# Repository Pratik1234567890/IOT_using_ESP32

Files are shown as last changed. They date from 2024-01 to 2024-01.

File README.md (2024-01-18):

# IOT_using_ESP32

This is four layer circuit board

# Schmematic


# 3D viewer


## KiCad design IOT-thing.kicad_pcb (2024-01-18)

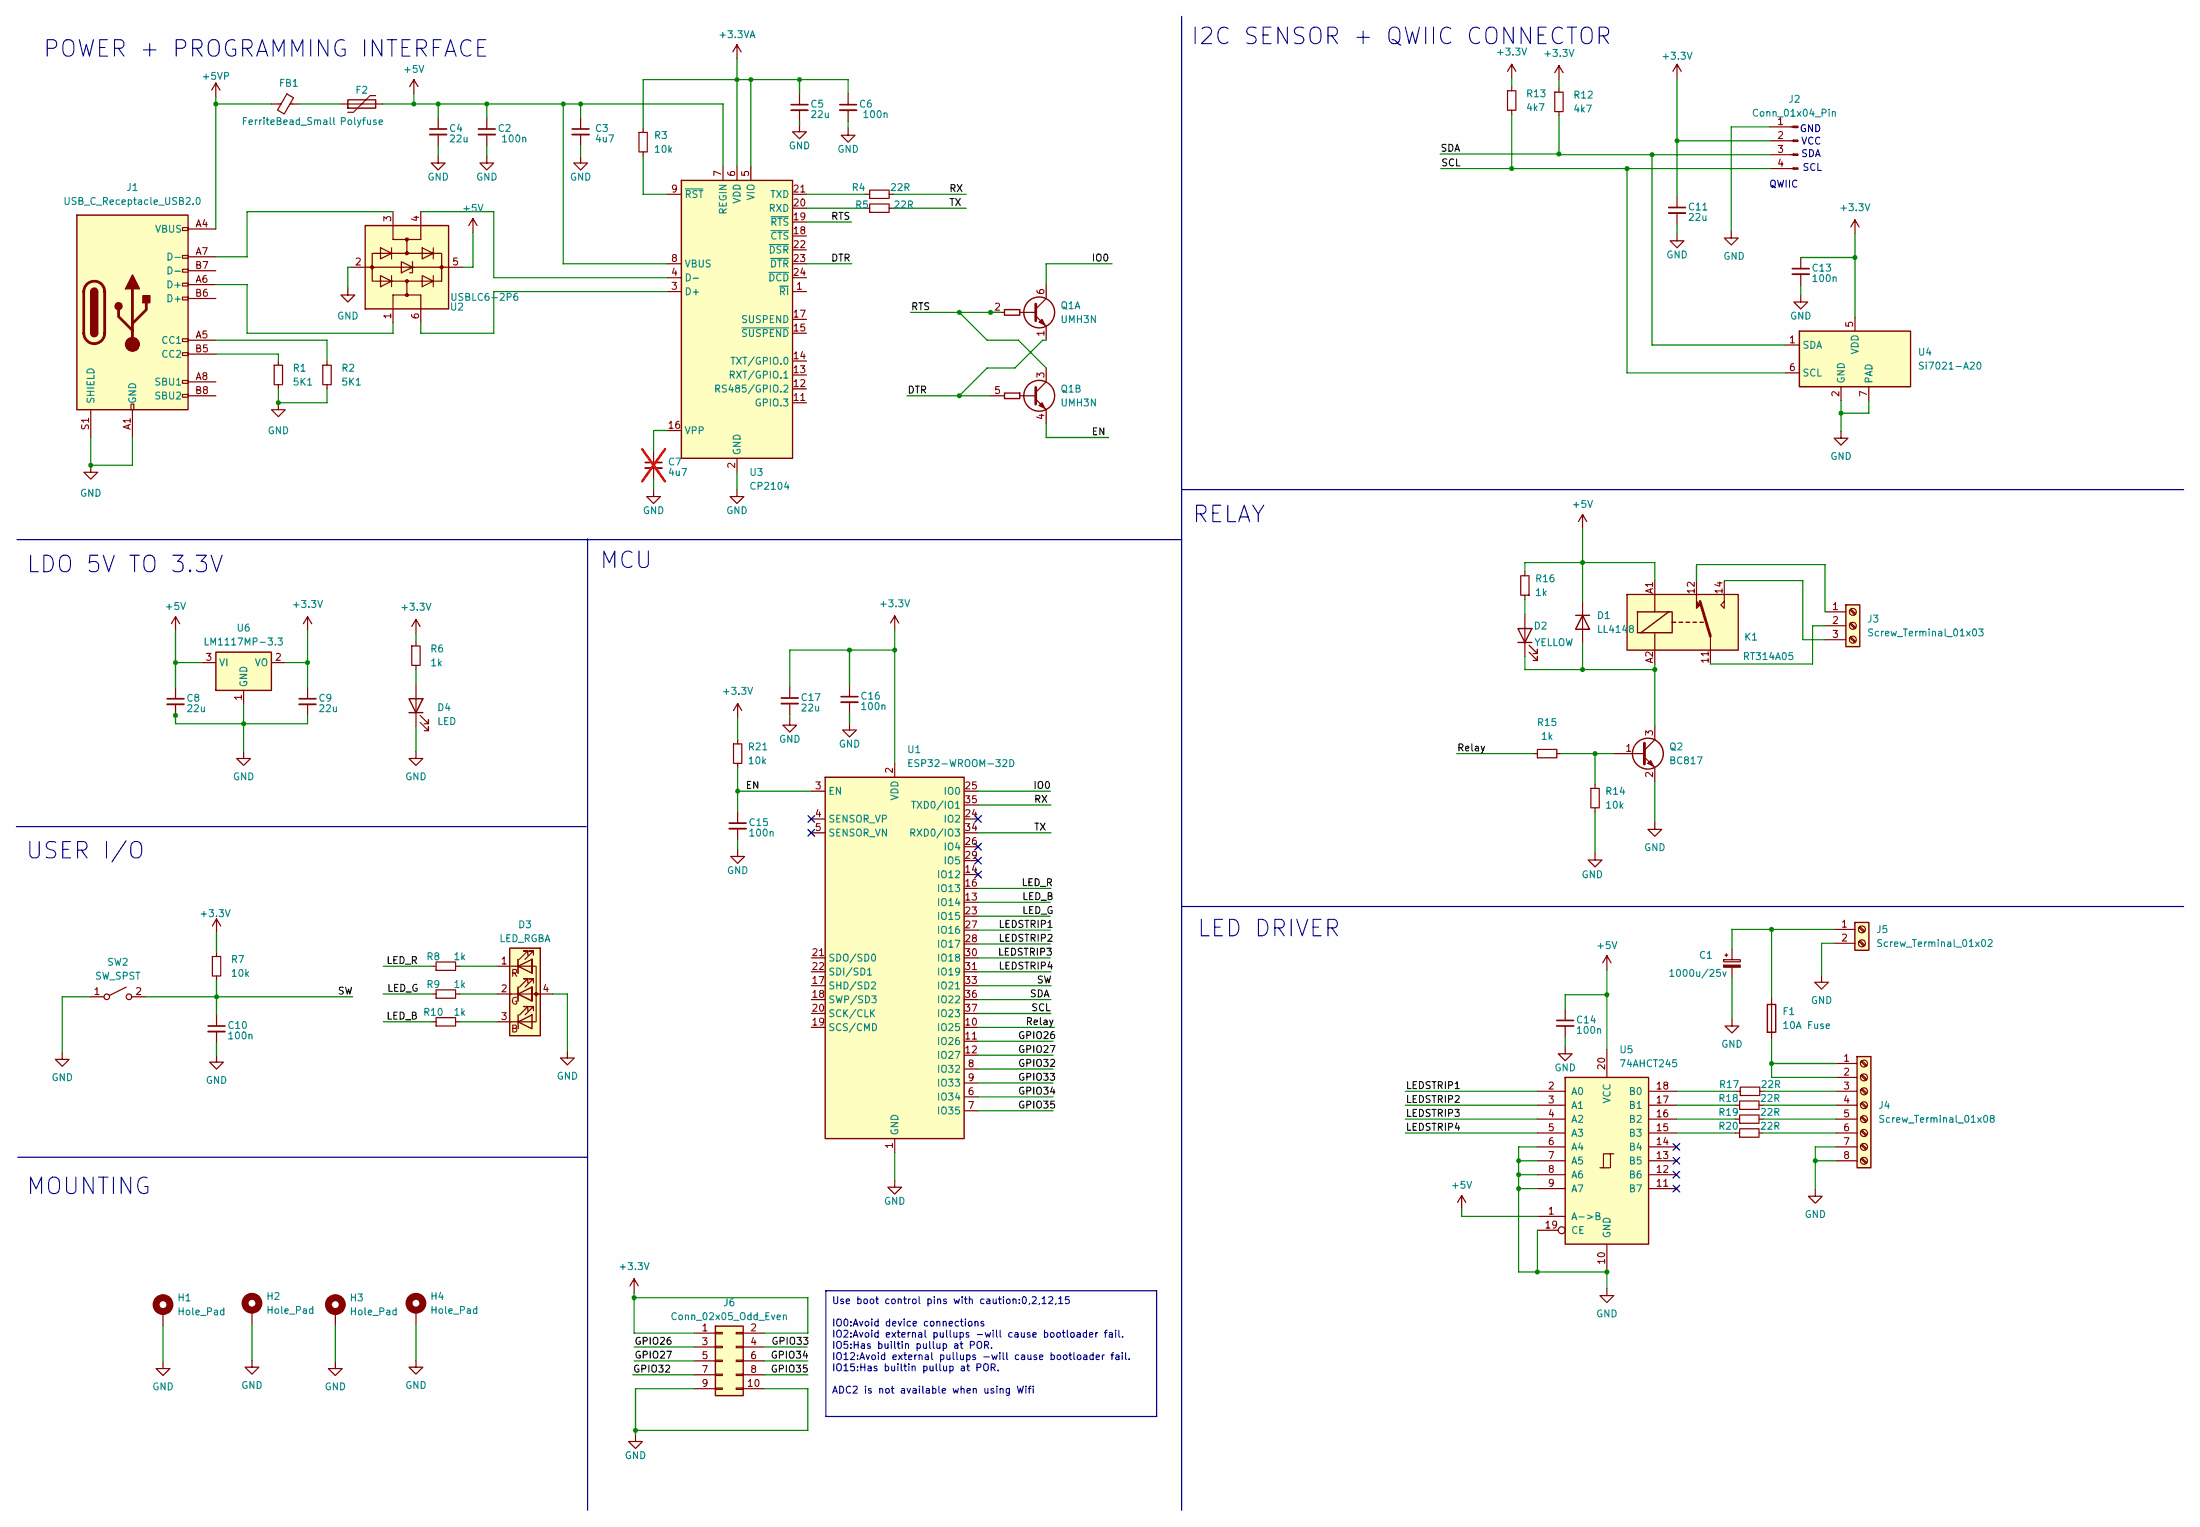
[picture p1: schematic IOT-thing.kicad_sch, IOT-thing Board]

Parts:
C1: 1000u/25v; CP_Radial_D10.0mm_P5.00mm
C2, C6, C10, C13, C14, C15, C16: 100n; C_0402_1005Metric_Pad0.74x0.62mm_HandSolder
C3: 4u7; C_0805_2012Metric_Pad1.18x1.45mm_HandSolder
C4, C5, C8, C9, C11, C17: 22u; C_0805_2012Metric_Pad1.18x1.45mm_HandSolder
C7: 4u7; C_0805_2012Metric_Pad1.18x1.45mm_HandSolder; not fitted
D1: LL4148; D_MiniMELF
D2: YELLOW; LED_0603_1608Metric_Pad1.05x0.95mm_HandSolder
D3: LED_RGBA; LED_RGB_Wuerth-PLCC4_3.2x2.8mm_150141M173100
D4: LED; LED_0603_1608Metric_Pad1.05x0.95mm_HandSolder
F1: 10A Fuse; Fuseholder_Clip-5x20mm_Bel_FC-203-22_Lateral_P17.80x5.00mm_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
F2: Polyfuse; Fuse_1206_3216Metric_Pad1.42x1.75mm_HandSolder
FB1: FerriteBead_Small; L_0603_1608Metric_Pad1.05x0.95mm_HandSolder
H1, H2, H3, H4: Hole_Pad; MountingHole_3.2mm_M3_Pad_Via
J1: USB_C_Receptacle_USB2.0; USB_C_Receptacle_HRO_TYPE-C-31-M-12
J2: Conn_01x04_Pin; JST_SH_SM04B-SRSS-TB_1x04-1MP_P1.00mm_Horizontal
J3: Screw_Terminal_01x03; TerminalBlock_Phoenix_MKDS-3-3-5.08_1x03_P5.08mm_Horizontal
J4: Screw_Terminal_01x08; TerminalBlock_Phoenix_MKDS-1,5-8_1x08_P5.00mm_Horizontal
J5: Screw_Terminal_01x02; TerminalBlock_Phoenix_MKDS-1,5-2-5.08_1x02_P5.08mm_Horizont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
J6: Conn_02x05_Odd_Even; PinHeader_2x05_P2.54mm_Vertical
K1: RT314A05; Relay_SPDT_Schrack-RT1-16A-FormC_RM5mm
Q1: UMH3N; SOT-363_SC-70-6
Q2: BC817; SOT-23
R1, R2: 5K1; R_0402_1005Metric_Pad0.72x0.64mm_HandSolder
R3, R7, R14, R21: 10k; R_0402_1005Metric_Pad0.72x0.64mm_HandSolder
R4, R5, R17, R18, R19, R20: 22R; R_0402_1005Metric_Pad0.72x0.64mm_HandSolder
R6, R8, R9, R10, R15, R16: 1k; R_0402_1005Metric_Pad0.72x0.64mm_HandSolder
R12, R13: 4k7; R_0402_1005Metric_Pad0.72x0.64mm_HandSolder
SW2: SW_SPST; SW_Push_1P1T_NO_6x6mm_H9.5mm
U1: ESP32-WROOM-32D
U2: USBLC6-2P6; SOT-666
U3: CP2104; QFN-24-1EP_4x4mm_P0.5mm_EP2.6x2.6mm
U4: Si7021-A20; DFN-6-1EP_3x3mm_P1mm_EP1.5x2.4mm
U5: 74AHCT245; DIP-20_W7.62mm
U6: LM1117MP-3.3; SOT-223-3_TabPin2

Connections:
+3.3V: C9.1, C11.1, C13.1, C16.1, C17.1, J2.2, J6.1, J6.2, R6.1, R7.1, R12.1, R13.1, R21.1, U1.2 (VDD), U4.5 (VDD), U6.2 (VO)
+3.3VA: C5.1, C6.1, R3.1, U3.5 (VIO), U3.6 (VDD)
+5V: C2.1, C3.1, C4.1, C8.1, C14.1, D1.1 (K), F2.2, K1.A1, R16.2, U2.5 (VBUS), U3.7 (REGIN), U3.8 (VBUS), U5.1 (A->B), U5.20 (VCC), U6.3 (VI)
+5VP: FB1.2, J1.A4 (VBUS), J1.A9 (VBUS), J1.B4 (VBUS), J1.B9 (VBUS)
/DTR: Q1.1 (E1), Q1.5 (B2), U3.23 (~DTR)
/EN: C15.1, Q1.4 (E2), R21.2, U1.3 (EN)
/GPIO26: J6.3, U1.11 (IO26)
/GPIO27: J6.5, U1.12 (IO27)
/GPIO32: J6.7, U1.8 (IO32)
/GPIO33: J6.4, U1.9 (IO33)
/GPIO34: J6.6, U1.6 (IO34)
/GPIO35: J6.8, U1.7 (IO35)
/IO0: Q1.6 (C1), U1.25 (IO0)
/LEDSTRIP1: U1.27 (IO16), U5.2 (A0)
/LEDSTRIP2: U1.28 (IO17), U5.3 (A1)
/LEDSTRIP3: U1.30 (IO18), U5.4 (A2)
/LEDSTRIP4: U1.31 (IO19), U5.5 (A3)
/LED_B: R10.1, U1.13 (IO14)
/LED_G: R9.1, U1.23 (IO15)
/LED_R: R8.1, U1.16 (IO13)
/RTS: Q1.2 (B1), Q1.3 (C2), U3.19 (~RTS)
/RX: R4.2, U1.35 (TXD0/IO1)
/Relay: R15.1, U1.10 (IO25)
/SCL: J2.4, R13.2, U1.37 (IO23), U4.6 (SCL)
/SDA: J2.3, R12.2, U1.36 (IO22), U4.1 (SDA)
/SW: C10.1, R7.2, SW2.2 (B), U1.33 (IO21)
/TX: R5.2, U1.34 (RXD0/IO3)
GND: C1.2, C2.2, C3.2, C4.2, C5.2, C6.2, C7.2, C8.2, C9.2, C10.2, C11.2, C13.2, C14.2, C15.2, C16.2, C17.2, D3.4 (A), D4.1 (K), H1.1, H2.1, H3.1, H4.1, J1.A1 (GND), J1.A12 (GND), J1.B1 (GND), J1.B12 (GND), J1.S1 (SHIELD), J2.1, J4.7, J4.8, J5.2, J6.9, J6.10, Q2.2 (E), R1.2, R2.2, R14.2, SW2.1 (A), U1.1 (GND), U1.15 (GND), U1.38 (GND), U1.39 (GND), U2.2 (GND), U3.2 (GND), U3.25 (GND), U4.2 (GND), U4.7 (PAD), U5.6 (A4), U5.7 (A5), U5.8 (A6), U5.9 (A7), U5.10 (GND), U5.19 (CE), U6.1 (GND)
unnamed: D1.2 (A), D2.1 (K), K1.A2, Q2.3 (C)
unnamed: D2.2 (A), R16.1
unnamed: D3.3 (BK), R10.2
unnamed: D3.2 (GK), R9.2
unnamed: D3.1 (RK), R8.2
unnamed: D4.2 (A), R6.2
unnamed: F2.1, FB1.1
unnamed: J1.A5 (CC1), R2.1
unnamed: J1.B5 (CC2), R1.1
unnamed: J1.A6 (D+), U2.1 (I/O1)
unnamed: J1.A7 (D-), U2.3 (I/O2)
unnamed: J3.1, K1.12
unnamed: J3.2, K1.11
unnamed: J3.3, K1.14
unnamed: F1.2, J4.1, J4.2
unnamed: J4.3, R17.2
unnamed: J4.4, R18.2
unnamed: J4.5, R19.2
unnamed: J4.6, R20.2
unnamed: C1.1, F1.1, J5.1
unnamed: Q2.1 (B), R14.1, R15.2
unnamed: U2.6 (I/O1), U3.3 (D+)
unnamed: U2.4 (I/O2), U3.4 (D-)
unnamed: R5.1, U3.20 (RXD)
unnamed: R4.1, U3.21 (TXD)
unnamed: C7.1, U3.16 (VPP)
unnamed: R3.2, U3.9 (~RST)
unnamed: R17.1, U5.18 (B0)
unnamed: R18.1, U5.17 (B1)
unnamed: R19.1, U5.16 (B2)
unnamed: R20.1, U5.15 (B3)

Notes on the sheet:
Use boot control pins with caution:0,2,12,15 IO0:Avoid device connections IO2:Avoid external pullups -will cause bootloader fail. IO5:Has builtin pullup at POR. IO12:Avoid external pullups -will cause bootloader fail. IO15:Has builtin pullup at POR. ADC2 is not available when using Wifi
RELAY
I2C SENSOR + QWIIC CONNECTOR
GND
USER I/O
LDO 5V TO 3.3V
POWER + PROGRAMMING INTERFACE
QWIIC
VCC
MCU
SDA
SCL
LED DRIVER
MOUNTING

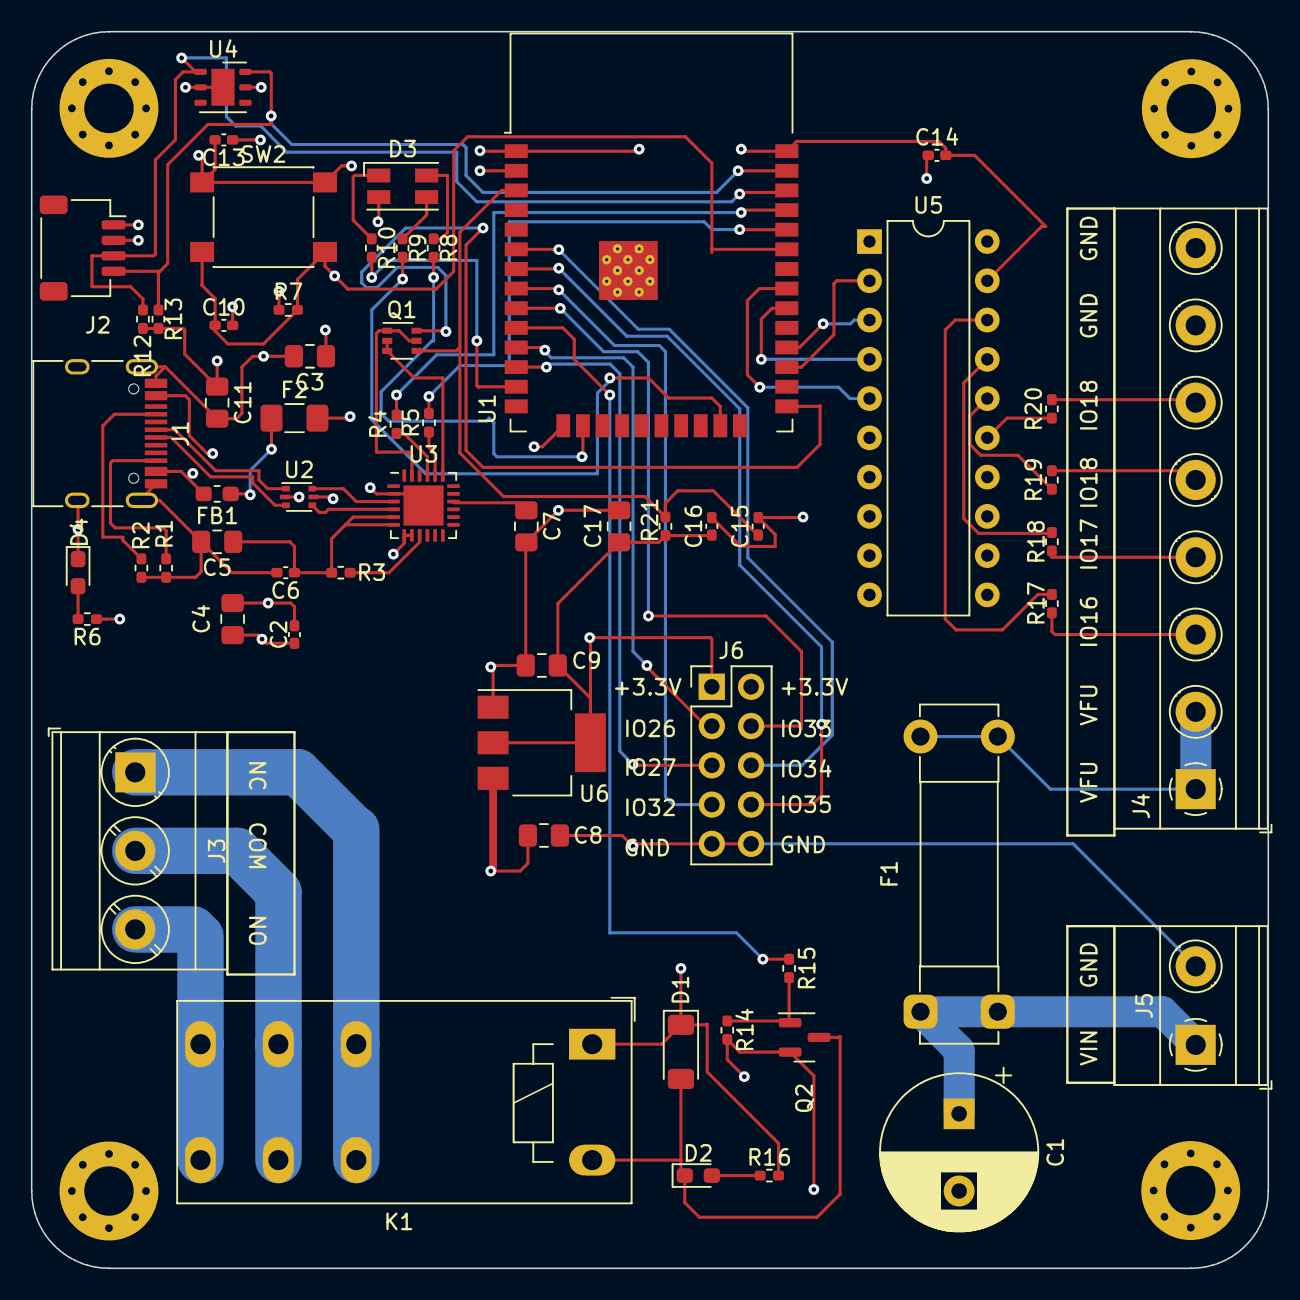
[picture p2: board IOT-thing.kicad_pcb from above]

Board: 4 copper layers, 80.0 x 80.0 mm, 63 parts (0 on the bottom side), 59 nets.
